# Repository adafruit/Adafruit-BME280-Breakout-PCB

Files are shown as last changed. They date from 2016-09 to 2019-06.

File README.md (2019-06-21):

## Adafruit BME280 Breakout PCB

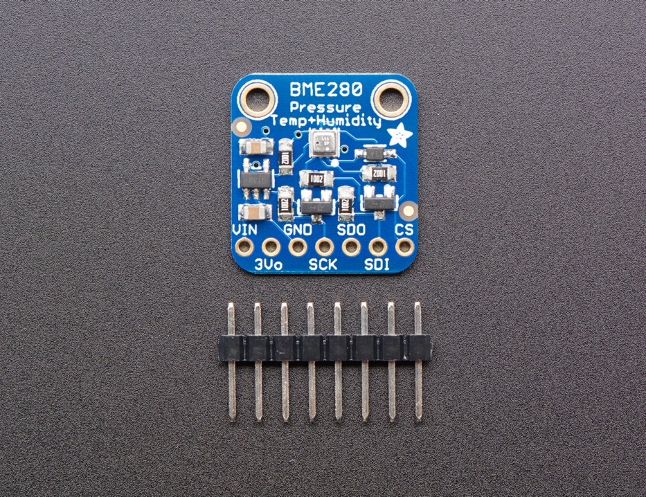
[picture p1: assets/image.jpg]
<a href="http://www.adafruit.com/products/2652"><br/>
Click here to purchase one from the Adafruit shop</a>

PCB files for the Adafruit BME280 Breakout. Format is EagleCAD schematic and board layout
* https://www.adafruit.com/product/2652

### Description

Bosch has stepped up their game with their new BME280 sensor, an environmental sensor with temperature, barometric pressure and humidity! This sensor is great for all sorts of weather/environmental sensing and can even be used in both I2C and SPI!

This precision sensor from Bosch is the best low-cost sensing solution for measuring humidity with ±3% accuracy, barometric pressure with ±1 hPa absolute accuraccy, and temperature with ±1.0°C accuracy. Because pressure changes with altitude, and the pressure measurements are so good, you can also use it as an altimeter with  ±1 meter or better accuracy!

The BME280 is the next-generation of sensors from Bosch, and is the upgrade to the BMP085/BMP180/BMP183 - with a low altitude noise of 0.25m and the same fast conversion time. It has the same specifications, but can use either I2C or SPI. For simple easy wiring, go with I2C. If you want to connect a bunch of sensors without worrying about I2C address collisions, go with SPI.

### License

Adafruit invests time and resources providing this open source design, please support Adafruit and open-source hardware by purchasing products from [Adafruit](https://www.adafruit.com)!

Designed by Limor Fried/Ladyada for Adafruit Industries.

Creative Commons Attribution/Share-Alike, all text above must be included in any redistribution. See license.txt for additional details.

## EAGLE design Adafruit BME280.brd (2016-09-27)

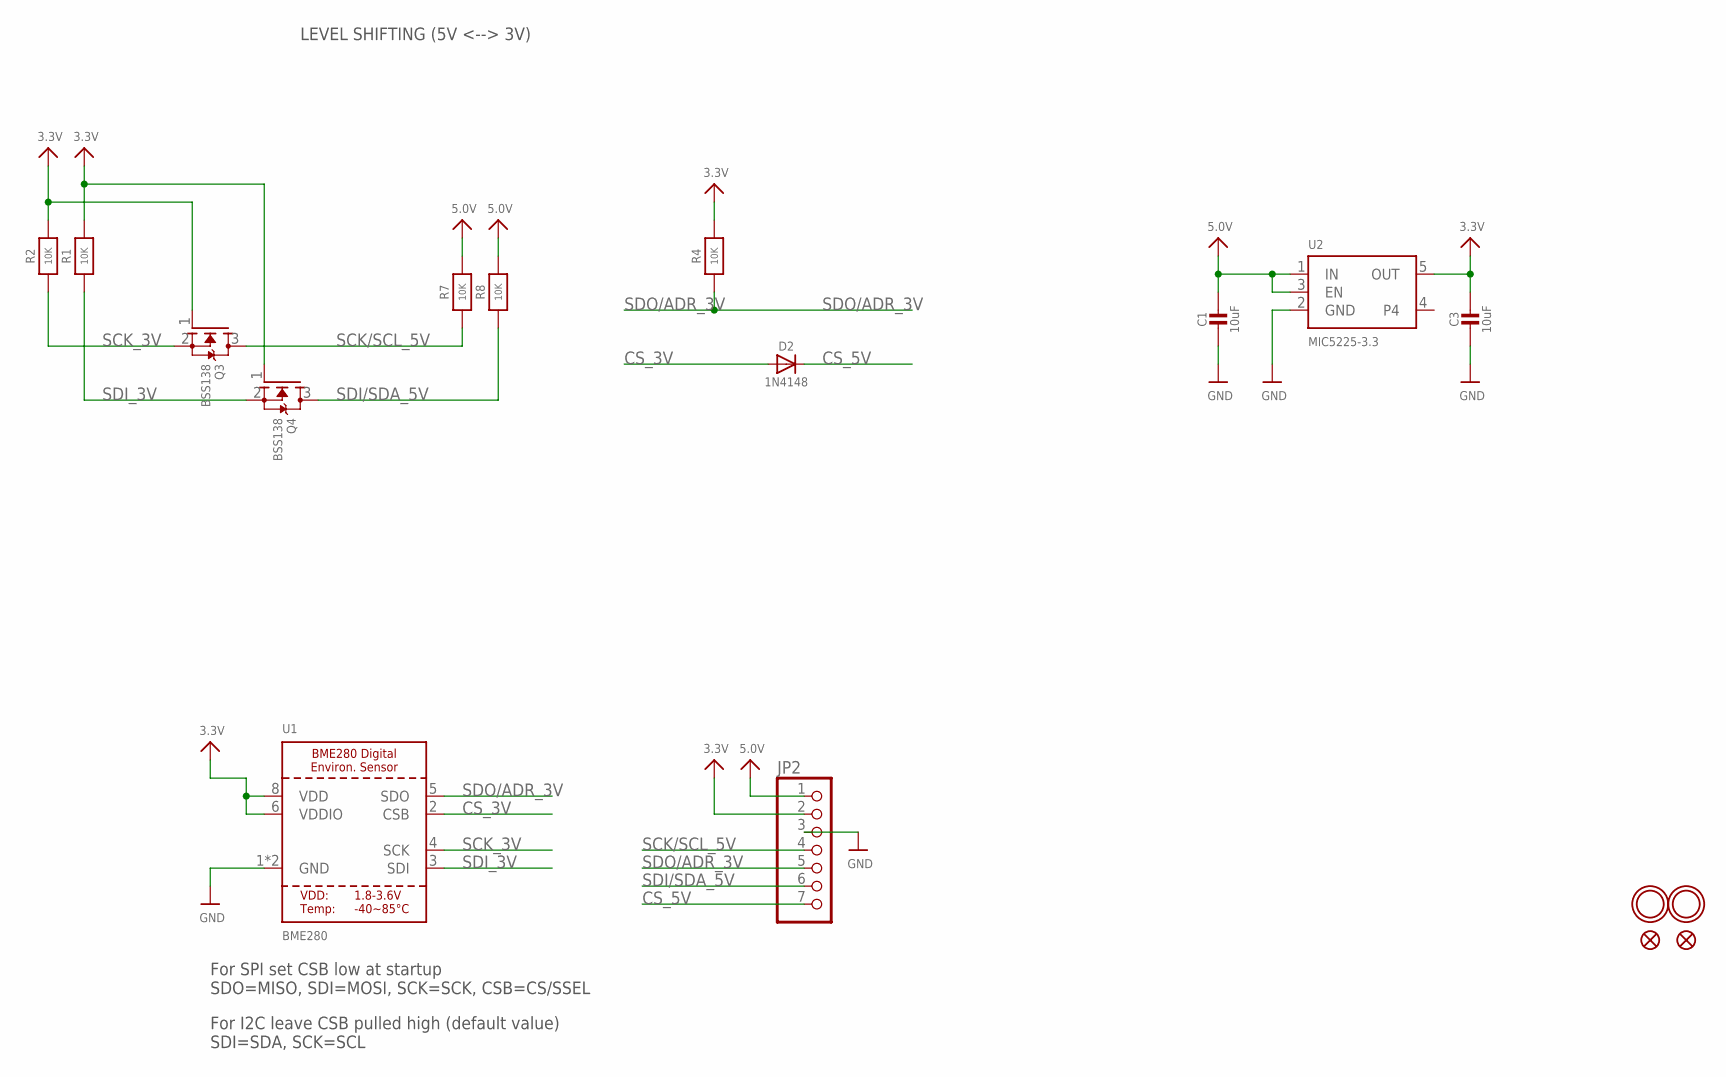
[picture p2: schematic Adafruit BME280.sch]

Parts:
C1, C3: 10uF; 0805-NO
D2: 1N4148; SOD-323
JP2: HEADER-1X770MIL; 1X07_ROUND_70
Q3, Q4: BSS138; SOT23-WIDE
R1, R2, R7, R8: 10K; 0805-NO
R4: 10K; _0805MP
U1: BME280
U2: MIC5225-3.3; SOT23-5
U$5, U$15: FIDUCIAL""; FIDUCIAL_1MM
U$7, U$8: MOUNTINGHOLE2.0; MOUNTINGHOLE_2.0_PLATED

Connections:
3.3V: C3.1, JP2.2, Q3.1 (G), Q4.1 (G), R1.2, R2.2, R4.2, U1.6 (VDDIO), U1.8 (VDD), U2.5 (OUT)
5.0V: C1.1, JP2.1, R7.2, R8.2, U2.1 (IN), U2.3 (EN)
CS_3V: D2.A, U1.2 (CSB)
CS_5V: D2.C, JP2.7
GND: C1.2, C3.2, JP2.3, U1.1 (GND), U1.7 (GND), U2.2 (GND)
SCK/SCL_5V: JP2.4, Q3.3 (D), R7.1
SCK_3V: Q3.2 (S), R2.1, U1.4 (SCK)
SDI/SDA_5V: JP2.6, Q4.3 (D), R8.1
SDI_3V: Q4.2 (S), R1.1, U1.3 (SDI)
SDO/ADR_3V: JP2.5, R4.1, U1.5 (SDO)

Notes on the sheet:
For SPI set CSB low at startup SDO=MISO, SDI=MOSI, SCK=SCK, CSB=CS/SSEL
For I2C leave CSB pulled high (default value) SDI=SDA, SCK=SCL
LEVEL SHIFTING (5V <--> 3V)

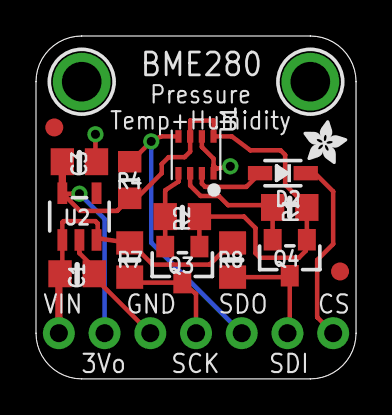
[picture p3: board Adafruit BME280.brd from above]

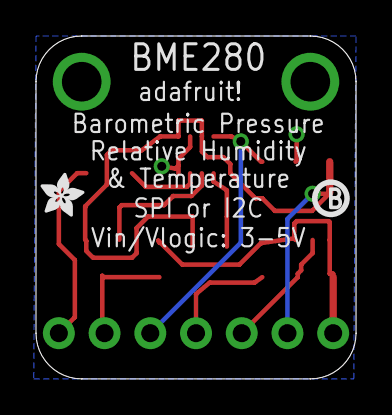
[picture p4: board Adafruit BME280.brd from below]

Board: 2 copper layers, 17.8 x 19.1 mm, 20 parts (2 on the bottom side), 10 nets.

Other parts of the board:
U$2, U$6: ADAFRUIT_2.5MM
U$20: PCBFEAT-REV-040
